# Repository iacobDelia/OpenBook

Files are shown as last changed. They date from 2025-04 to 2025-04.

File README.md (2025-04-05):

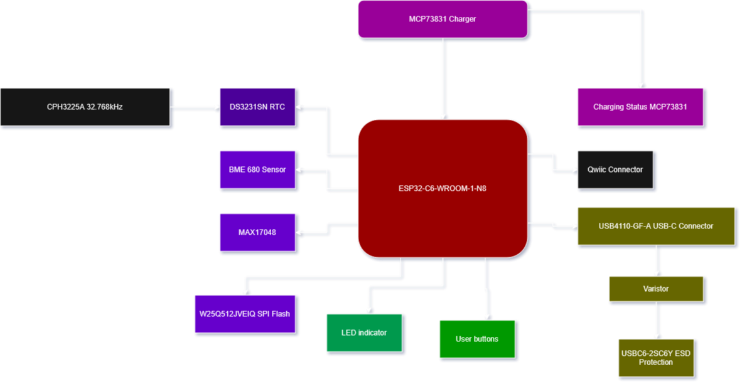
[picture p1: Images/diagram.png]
Diagrama openbook

# Bill of Materials
| Componenta | Link | Datasheet
| --- | --- |---|
| ESP32_WROVER_EAGLE-LTSPICE_RR0402  | https://www.snapeda.com/parts/RC0402FR-07226RL/Yageo/view-part/ |https://www.snapeda.com/parts/RC0402FR-07226RL/Yageo/datasheet/
| QWIIC_CONNECTORJS-1MM | https://www.snapeda.com/parts/PRT-14417/SparkFun/view-part/ |https://www.snapeda.com/parts/PRT-14417/SparkFun%20Electronics/datasheet/
|BUTTON_CUSYOMV1|https://industry.panasonic.com/global/en/downloads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|https://industry.panasonic.com/global/en/downloads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
|ESP32_WROVER_EAGLE-LTSPICE_CC0402|https://componentsearchengine.com/part-view/CC0402MRX5R5BB106/YAGEO|https://componentsearchengine.com/Datasheets/2/CC0402MRX5R5BB106.pdf
|CPH3225A|https://www.snapeda.com/parts/CPH3225A/Seiko+Instruments/view-part/?ref=eda|https://www.snapeda.com/parts/CPH3225A/Seiko%20Instruments/datasheet/|
|ADAFRUIT_LEDCHIP-LED0603|https://www.snapeda.com/parts/KP-1608SURCK/Kingbright/view-part/?ref=search&t=LED%200603|https://www.snapeda.com/parts/KP-1608SURCK/Kingbright/datasheet/
|112A-TAAR-R03_ATTEND|https://store.comet.bg/en/Catalogue/Product/43497/|https://store.comet.bg/en/Catalogue/Product/43497/|
|744043680IND_4828-WE-TPC_WRE|https://www.digikey.sg/en/models/1638515|https://www.we-online.com/components/products/datasheet/744043680.pdf
|BD5229G-TR|https://componentsearchengine.com/part-view/BD5229G-TR/ROHM%20Semiconductor|https://datasheet.datasheetarchive.com/originals/distributors/Datasheets_SAMA/f2b9741ef86007909f138d561a359946.pdf|
|CPH3225A|https://www.snapeda.com/parts/CPH3225A/Seiko+Instruments/view-part/?ref=eda|https://www.snapeda.com/parts/CPH3225A/Seiko%20Instruments/datasheet/|
|DS3231SN|https://www.snapeda.com/parts/DS3231SN%23/Analog+Devices/view-part/?ref=eda|https://www.snapeda.com/parts/DS3231SN%23/Analog%20Devices/datasheet/|
|ESP32-C6-WROOM-1-N8|https://www.snapeda.com/parts/ESP32-C6-WROOM-1-N8/Espressif+Systems/view-part/?ref=eda|https://www.snapeda.com/parts/ESP32-C6-WROOM-1-N8/Espressif%20Systems/datasheet/
|MCP73831|https://www.digikey.com/en/models/1874108|https://ww1.microchip.com/downloads/aemDocuments/documents/APID/ProductDocuments/DataSheets/MCP73831-Family-Data-Sheet-DS20001984H.pdf|
|ESP32_WROVER_BME680_BME680|https://www.snapeda.com/parts/BME680/Bosch/view-part/?welcome=home|https://www.snapeda.com/parts/BME680/Bosch%20Sensortec/datasheet/|
|ESP32_WROVER_EAGLE-LTSPICE_CC0402|https://componentsearchengine.com/Datasheets/2/CC0402MRX5R5BB106.pdf|https://componentsearchengine.com/part-view/CC0402MRX5R5BB106/YAGEO|
|ESP32_WROVER_SPARKFUN-DISCRETESEMI_MOSFET_PCH-DMG2305UX-7|https://componentsearchengine.com/part-view/DMG2305UX-7/Diodes%20Incorporated|https://www.diodes.com//assets/Datasheets/DMG2305UX.pdf|
|ESP32C6_VARISTORCN1812|https://www.mouser.co.uk/ProductDetail/EPCOS-TDK/B72520T0350K062?qs=dEfas%2FXlABIszF52uu7vrg%3D%3D|https://www.tdk-electronics.tdk.com/inf/75/db/CTVS_14/Surge_protection_series.pdf|
|FH34SRJ-24S-0.5SH_99_|https://componentsearchengine.com/part-view/XC6220A331MR-G/Torex|https://product.torexsemi.com/system/files/series/xc6220.pdf|
|MAX17048G+T10|https://www.snapeda.com/parts/MAX17048G+T10/Analog+Devices/view-part/?ref=eda|https://www.snapeda.com/parts/MAX17048G+T10/Analog%20Devices/datasheet/|
|MBR0530|https://ro.mouser.com/ProductDetail/KYOCERA-AVX/SD0805S020S1R0?qs=jCA%252BPfw4LHbpkAoSnwrdjw%3D%3D|https://ro.mouser.com/datasheet/2/40/schottky-3165252.pdf|
|PGB1010603MR|https://www.snapeda.com/parts/PGB1010603MR/Littelfuse/view-part/?ref=eda|https://www.snapeda.com/parts/PGB1010603MR/Littelfuse%20Inc./datasheet/|
|RCL_CPOL-EUCT3528|https://ro.mouser.com/ProductDetail/Vishay-Sprague/TR3B106K025C1300?qs=jCGqFXxTmLdffnuDkXzk1g%3D%3D|https://www.vishay.com/docs/40080/tr3.pdf|
|SAMACSYS_PARTS_USB4110-GF-A|https://componentsearchengine.com/part-view/USB4110-GF-A/GCT%20(GLOBAL%20CONNECTOR%20TECHNOLOGY)|https://gct.co/files/drawings/usb4110.pdf|
|SI1308EDL-T1-GE3|https://componentsearchengine.com/part-view/SI1308EDL-T1-GE3/Vishay|https://componentsearchengine.com/Datasheets/1/SI1308EDL-T1-GE3.pdf|
|SJ|https://grabcad.com/library/solder-jumpers-1||
|USBLC6-2SC6Y|https://www.snapeda.com/parts/USBLC6-2SC6Y/STMicroelectronics/view-part/?ref=eda|https://www.snapeda.com/parts/USBLC6-2SC6Y/STMicroelectronics/datasheet/|
|W25Q512JVEIQ|https://www.snapeda.com/parts/W25Q512JVEIQ/Winbond+Electronics/view-part/?ref=eda|https://www.snapeda.com/parts/W25Q512JVEIQ/Winbond%20Electronics/datasheet/|
|XC6220A331MR-G|https://componentsearchengine.com/part-view/XC6220A331MR-G/Torex|https://product.torexsemi.com/system/files/series/xc6220.pdf|

# Functionalitati Hardware
## Microcontroller
Microcontroller principal: ESP32-C6-WROOM-1-N8

    Interfețe: UART, I²C, SPI, GPIO, ADC, PWM, USB 2.0

    Comunicare wireless: WiFi 6 (802.11ax), Bluetooth 5.0 Low Energy, Zigbee & Thread (prin IEEE 802.15.4)

    Memorie: 8 MB Flash

    Rol: Controler central ce gestionează comunicația cu toate perifericele și modulele externe. Este responsabil pentru achiziția de date, procesare și trimiterea lor către o interfață (de ex. server sau aplicație mobilă).

Ceas în timp real: DS3231SN

    Tip: RTC (Real-Time Clock) cu compensare termică

    Interfață: I²C

    Rol: Asigură măsurarea precisă a timpului, util pentru timestamp-ul datelor colectate de senzori.

Senzor de mediu: BME680

    Măsoară: Temperatură, presiune, umiditate și compuși organici volatili (VOC)

    Interfață: I²C (poate fi și SPI)

    Rol: Oferă date esențiale de mediu pentru aplicații IoT, monitorizare atmosferică etc.

### Managementul energiei
MCP73831

    Rol: Încărcător Li-Ion / Li-Po

    Interfață: Analogică, configurabilă prin rezistențe externe

    Caracteristici: Control al curentului de încărcare, protecții integrate

MAX17048G+T10

    Rol: Fuel Gauge IC

    Interfață: I²C

    Funcții: Măsoară tensiunea și estimează nivelul bateriei (SoC - state of charge)

Memorie externă: W25Q512JVEIQ

    Tip: NOR Flash, 512Mbit

    Interfață: SPI

    Rol: Stocare de date (loguri, configurări, firmware OTA)

Protecție și integritate electrică

    USBLC6-2SC6Y – Protecție ESD pentru liniile USB

    PGB1010603MR – Protecție împotriva descărcărilor electrostatice (ESD)

    SI1308EDL-T1-GE3 / DMG2305UX-7 – MOSFET pentru comutarea energiei sau protecție

    BD5229G-TR – Regulator LDO de 2.9V

    Varistor CN1812 (B72520T0350K062) – Protecție la supratensiuni

    Diodă Schottky (MBR0530) – Prevenirea curenților inversi

Conectivitate externă

    QWIIC_CONNECTORJS-1MM – Conector pentru I²C (QWIIC standard, modular, plug-and-play)

    SAMACSYS_PARTS_USB4110-GF-A – USB-C pentru alimentare și comunicare

    112A-TAAR-R03_ATTEND – Conector placă-la-placă

    SJ (Solder Jumpers) – Permite configurarea opțională a traseelor prin punți de lipit

Feedback vizual & control

    ADAFRUIT_LEDCHIP-LED0603 (KP-1608SURCK) – LED de status

    BUTTON_CUSYOMV1 (EVQPUJ02K) – Buton mecanic, folosit pentru reset, input de utilizator sau inițierea unei funcții

# Total consum
Componentă|	Consum tipic|
|-------|----------|
|ESP32-C6|	~130mA |
|BME680|	~3.1µA (low power)|	
|DS3231SN|	~200nA	|
|MAX17048|	~23µA	|
|MCP73831|	până la 500mA|	
|LED-uri|	~2-10mA	|

Total estimativ în mod activ: ~150-180mA

## Conexiuni componente la pini ESP32-C6
RTC – DS3231SN

    Interfață: I²C

    Pini ESP32-C6 folosiți:

        GPIO8 – I²C SDA

        GPIO9 – I²C SCL

    Motiv: GPIO8 și GPIO9 sunt frecvent utilizați pentru magistrala I²C pe ESP32-C6 deoarece pot fi configurate software și sunt ușor de accesat. SDA și SCL trebuie trase cu rezistențe de pull-up (tipic 4.7kΩ).

Senzor mediu – BME680

    Interfață: I²C (partajează magistrala cu DS3231)

    Pini ESP32-C6 folosiți:

        GPIO8 – SDA

        GPIO9 – SCL

    Motiv: Magistrala I²C permite conectarea în paralel a mai multor dispozitive, fiecare având adresă unică.

Fuel Gauge – MAX17048

    Interfață: I²C

    Pini: Aceeași magistrală I²C (GPIO8 & GPIO9)

    Motiv: MAX17048 are adresă I²C fixă, deci trebuie verificat să nu fie conflict cu celelalte două componente (nu e cazul aici).

Memorie externă – W25Q512JVEIQ

    Interfață: SPI

    Pini ESP32-C6:

        GPIO4 – SPI MOSI

        GPIO5 – SPI MISO

        GPIO6 – SPI CLK

        GPIO7 – SPI CS

    Motiv: Aceste GPIO-uri sunt pinii SPI hardware dedicați pe ESP32-C6 și asigură performanță maximă și compatibilitate cu interfața SPI (QSPI în cazul memoriei).

LED (KP-1608SURCK)

    Interfață: GPIO (digital out, cu rezistor în serie)

    Pin:

        GPIO3 – LED Control

    Motiv: GPIO3 este un pin liber cu capabilități PWM, ceea ce permite și control al intensității (dimming), nu doar on/off.

Buton (EVQPUJ02K)

    Interfață: GPIO + Pull-up intern

    Pin:

        GPIO0 – Buton utilizator

    Motiv: GPIO0 este adesea folosit și pentru bootloader/reset (cu atenție la stări în timpul pornirii). E un pin convenabil pentru input digital.

Qwiic Connector (I²C extensibil)

    Pini: I²C SDA/SCL partajați

        GPIO8 – SDA

        GPIO9 – SCL

    Motiv: Qwiic folosește același protocol I²C, deci toate dispozitivele compatibile Qwiic se pot lega în paralel la acești pini.

MCP73831 – Încărcare baterie

    Pini:

        VBUS / USB – Alimentare 5V

        STAT pin legat la GPIO10 (monitorizare charging status)

    Motiv: GPIO10 este configurabil ca input pentru a citi starea de încărcare (LED status al MCP73831 conectat la pinul STAT).

MAX17048 – Fuel Gauge

    Alimentare + I²C (vezi mai sus)

    INT (optional): Conectat la GPIO1

    Motiv: GPIO1 poate fi configurat cu întrerupere (interrupt) pentru notificări despre nivelul bateriei critic/scăzut.

USB4110-GF-A – USB-C connector

    Funcție: Alimentare 5V și comunicație

    Pin USB D+ / D- conectați la:

        GPIO18 – USB D+

        GPIO19 – USB D-

    Motiv: ESP32-C6 are suport USB nativ. Aceste GPIO-uri sunt default pentru perifericul USB Device.

Alte conexiuni:

    CPH3225A (oscilator 32.768 kHz) – utilizat pentru RTC, conectat la pinul dedicat RTC_CLKIN (sau la DS3231 dacă nu e folosit direct de MCU)

    MOSFET & diodă Schottky – control și protecție, comutarea pinilor GPIO pentru pornire/oprire module

    Varistor, rezistențe, condensatori – pasive pentru protecție, filtrare și stabilitate electrică (nu folosesc GPIO-uri direct)

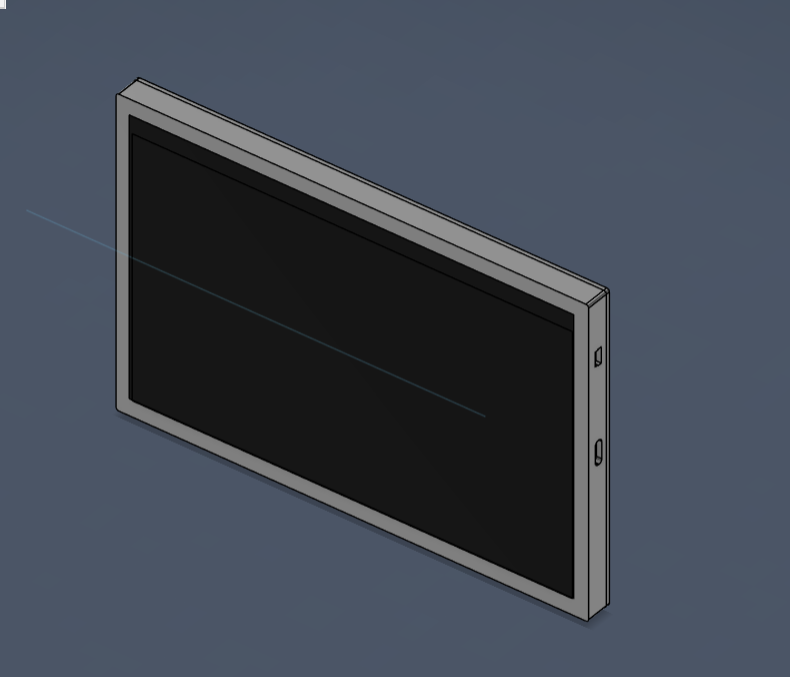
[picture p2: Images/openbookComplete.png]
Render complet

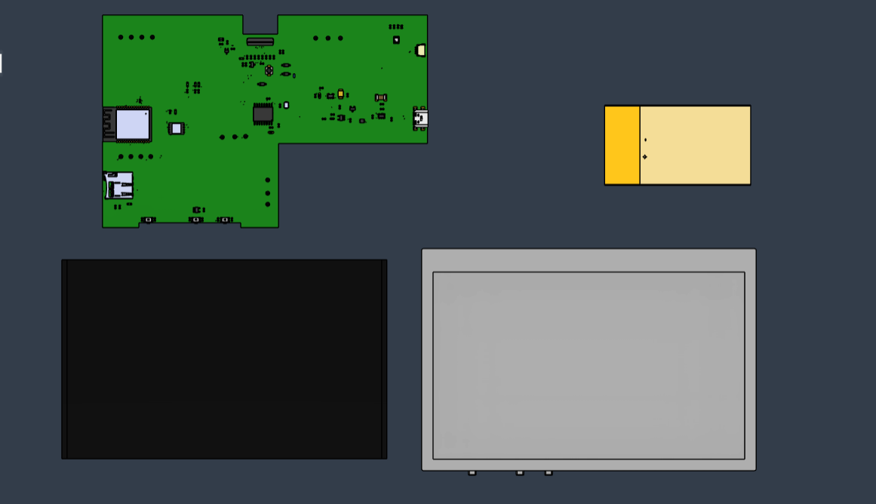
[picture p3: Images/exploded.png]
Exploded view

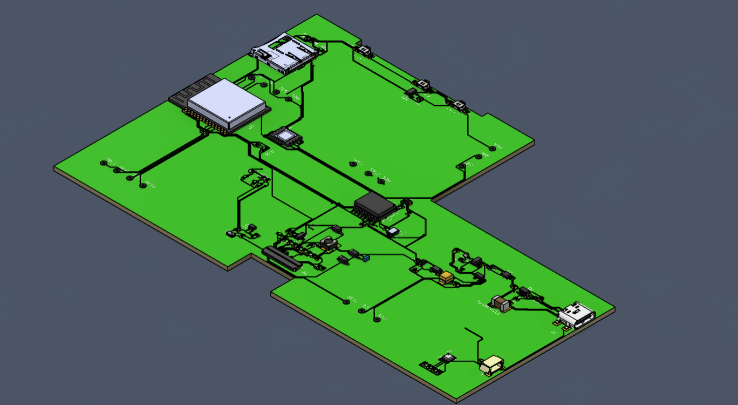
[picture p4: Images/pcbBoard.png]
Pcb


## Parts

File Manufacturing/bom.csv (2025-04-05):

Qty | Value | Device | Package | Parts | Description | ARROW_PART_NUMBER | ARROW_PRICE-STOCK | AVAILABILITY | CENTROID_NOT_SPECIFIED | CHECK_PRICES | COPYRIGHT | DATASHEET | DESCRIPTION | DIGIKEY_DESCRIPTION | DIGIKEY_PART_NUMBER | HEIGHT | LEAD_FREE | MANUFACTURER_NAME | MANUFACTURER_PART_NUMBER | MF | MFR_NAME | MOUSER_PART_NUMBER | MOUSER_PRICE-STOCK | MOUSER_TESTING_PART_NUMBER | MOUSER_TESTING_PRICE-STOCK | MP | MPN | PACKAGE | POPULARITY | PREFIX | PRICE | PROD_ID | PURCHASE-URL | ROHS | SNAPEDA_LINK | SPICEMODEL | SPICEPREFIX | TEMPERATURE_RANGE_HIGH | TEMPERATURE_RANGE_LOW | TP_SIGNAL_NAME | VALUE
1 |  | ADAFRUIT_LEDCHIP-LED0603 | ADAFRUIT_CHIP-LED0603 | CHG_LED | LED
1 |  | SJ | SJ | SJ1 | SMD solder JUMPER |  |  |  |  |  |  |  |  |  |  |  |  |  |  |  |  |  |  |  |  |  |  |  | 3
8 | 0.1uF/50V | ESP32_WROVER_EAGLE-LTSPICE_CC0402 | ESP32_WROVER_EAGLE-LTSPICE_C0402 | EPD_C5, EPD_C6, EPD_C7, EPD_C8, EPD_C9, EPD_C10, EPD_C11, EPD_C12 | CAPACITOR, European symbol |  |  |  |  |  |  |  |  |  |  |  |  |  |  |  |  |  |  |  |  |  |  |  |  |  |  |  |  |  |  | NONE | C
1 | 0.47 | ESP32_WROVER_EAGLE-LTSPICE_RR0402 | ESP32_WROVER_EAGLE-LTSPICE_R0402 | R3 | RESISTOR, European symbol |  |  |  |  |  |  |  |  |  |  |  |  |  |  |  |  |  |  |  |  |  |  |  |  |  |  |  |  |  |  | NONE | R
1 | 100K | ESP32_WROVER_EAGLE-LTSPICE_RR0402 | ESP32_WROVER_EAGLE-LTSPICE_R0402 | R1_PWRUSB | RESISTOR, European symbol
6 | 100nF | ESP32_WROVER_EAGLE-LTSPICE_CC0402 | ESP32_WROVER_EAGLE-LTSPICE_C0402 | C1, C2, C4_USB, C7, C8, C_DELAY | CAPACITOR, European symbol |  |  |  |  |  |  |  |  |  |  |  |  |  |  |  |  |  |  |  |  |  |  |  |  |  |  |  |  |  |  | NONE | C
1 | 100uF TANT | RCL_CPOL-EUCT3528 | RCL_CT3528 | C11 | POLARIZED CAPACITOR, European symbol |  |  |  |  |  |  |  |  |  |  |  |  |  |  |  |  |  |  |  |  |  |  |  | 0 |  |  |  |  |  |  |  | C
13 | 10K | ESP32_WROVER_EAGLE-LTSPICE_RR0402 | ESP32_WROVER_EAGLE-LTSPICE_R0402 | R1_PINH, R1_PINH1, R2-PINH, R2-PINH1, R5, R6, R7, R8, R9, R10, R_BOOT, R_CHANGE, R_RESET | RESISTOR, European symbol
2 | 10k | ESP32_WROVER_EAGLE-LTSPICE_RR0402 | ESP32_WROVER_EAGLE-LTSPICE_R0402 | R1, R_CL1 | RESISTOR, European symbol
1 | 10k | ESP32_WROVER_EAGLE-LTSPICE_RR0402 | ESP32_WROVER_EAGLE-LTSPICE_R0402 | R4 | RESISTOR, European symbol |  |  |  |  |  |  |  |  |  |  |  |  |  |  |  |  |  |  |  |  |  |  |  |  |  |  |  |  |  |  | NONE | R
4 | 10uF | ESP32_WROVER_EAGLE-LTSPICE_CC0402 | ESP32_WROVER_EAGLE-LTSPICE_C0402 | C3, C5, C6, C10 | CAPACITOR, European symbol |  |  |  |  |  |  |  |  |  |  |  |  |  |  |  |  |  |  |  |  |  |  |  |  |  |  |  |  |  |  | NONE | C
1 | 112A-TAAR-R03_ATTEND | 112A-TAAR-R03_ATTEND | 112ATAARR03ATTEND | J4 | Micro SD Card Socket, Push-Push Type, Top Mount, SMT, H=1.83mm, 10u |  |  |  |  |  |  |  | Micro SD Card Socket | Push-Push Type | Top Mount | SMT | H=1.83mm | 10u |  |  | 1.9mm |  | ATTEND | 112A-TAAR-R03 ATTEND
1 | 15 | ESP32_WROVER_EAGLE-LTSPICE_RR0402 | ESP32_WROVER_EAGLE-LTSPICE_R0402 | R_CAPACITOR | RESISTOR, European symbol
2 | 1uF/50V | ESP32_WROVER_EAGLE-LTSPICE_CC0402 | ESP32_WROVER_EAGLE-LTSPICE_C0402 | EPD_C1, EPD_C2 | CAPACITOR, European symbol |  |  |  |  |  |  |  |  |  |  |  |  |  |  |  |  |  |  |  |  |  |  |  |  |  |  |  |  |  |  | NONE | C
1 | 2.2 | ESP32_WROVER_EAGLE-LTSPICE_RR0402 | ESP32_WROVER_EAGLE-LTSPICE_R0402 | R2 | RESISTOR, European symbol
1 | 200 | ESP32_WROVER_EAGLE-LTSPICE_RR0402 | ESP32_WROVER_EAGLE-LTSPICE_R0402 | R1_BAT | RESISTOR, European symbol
2 | 20V/4.2A/52mO/1.4W | ESP32_WROVER_SPARKFUN-DISCRETESEMI_MOSFET_PCH-DMG2305UX-7 | ESP32_WROVER_SPARKFUN-DISCRETESEMI_SOT23-3 | Q2, Q3 | P-channel MOSFETs |  |  |  |  |  |  |  |  |  |  |  |  |  |  |  |  |  |  |  |  |  |  |  |  |  |  | TRAN-14388 |  |  |  |  |  |  |  |  | 20V/4.2A/52mO/1.4W
1 | 2k | ESP32_WROVER_EAGLE-LTSPICE_RR0402 | ESP32_WROVER_EAGLE-LTSPICE_R0402 | R2_BAT | RESISTOR, European symbol
5 | 4.7uF | ESP32_WROVER_EAGLE-LTSPICE_CC0402 | ESP32_WROVER_EAGLE-LTSPICE_C0402 | C1_BAT, C1_BAT1, C1_BAT2, C2_BAT, C5_USB | CAPACITOR, European symbol |  |  |  |  |  |  |  |  |  |  |  |  |  |  |  |  |  |  |  |  |  |  |  |  |  |  |  |  |  |  | NONE | C
1 | 4.7uF/25V | ESP32_WROVER_EAGLE-LTSPICE_CC0402 | ESP32_WROVER_EAGLE-LTSPICE_C0402 | C4 | CAPACITOR, European symbol |  |  |  |  |  |  |  |  |  |  |  |  |  |  |  |  |  |  |  |  |  |  |  |  |  |  |  |  |  |  | NONE | C
1 | 5K1 | ESP32_WROVER_EAGLE-LTSPICE_RR0402 | ESP32_WROVER_EAGLE-LTSPICE_R0402 | R2-USB1 | RESISTOR, European symbol
1 | 5k1 | ESP32_WROVER_EAGLE-LTSPICE_RR0402 | ESP32_WROVER_EAGLE-LTSPICE_R0402 | R2-USB | RESISTOR, European symbol
1 | 68uH | 744043680IND_4828-WE-TPC_WRE | IND_4828-WE-TPC_WRE | L1 |  |  |  |  |  |  | Copyright (C) 2024 Ultra Librarian. All rights reserved. |  |  |  |  |  |  |  | 744043680 |  | Wurth Electronics
1 | BD5229G-TR | BD5229G-TR | SOT95P280X125-5N | IC1 | Voltage Detector with Adjustable Delay Time: CMOS processes are utilized to develop high precision, low current consumption CMOS reset ICs that allow arbitrary setting of the delay time. The extensive lineup includes both Nch Open Drain and CMOS output types in a wide range of detection voltages (from 2.3V to 6.0V, in 0.1V steps), enabling selection of the ideal solution based on customer requirements. In addition, the entire series is of course both lead-free and RoHS-compliant. |  |  |  |  |  |  |  | Voltage Detector with Adjustable Delay Time: CMOS processes are utilized to develop high precision | low current consumption CMOS reset ICs that allow arbitrary setting of the delay time. The extensive lineup includes both Nch Open Drain and CMOS output types in a wide range of detection voltages (from 2.3V to 6.0V | in 0.1V steps) | enabling selection of the ideal solution based on customer requirements. In addition | the entire series is of course both lead-free and RoHS-compliant. |  |  | 1.25mm |  | ROHM Semiconductor | BD5229G-TR |  |  | 755-BD5229G-TR | https://www.mouser.co.uk/ProductDetail/ROHM-Semiconductor/BD5229G-TR?qs=4kLU8WoGk0vvnhrrYwdszw%3D%3D
3 | BUTTON_CUSYOMV1 | BUTTON_CUSYOMV1 | MYBUTTON | BOOT_BUTTON, CHANGE_BUTTON, RESET_BUTTON
1 | CPH3225A | CPH3225A | CAPCP3225X100N | C10_SUPERCAP | Cap 0.011F 3.3V 1210 Flat Check availability |  |  | Not in stock |  | https://www.snapeda.com/parts/CPH3225A/Seiko+Instruments/view-part/?ref=eda |  |  | 11 mF (EDLC) Supercapacitor 3.3 V 1210 (3225 Metric) - - |  |  |  |  |  |  | Seiko Instruments |  |  |  |  |  | CPH3225A |  | 1210 Seiko |  |  | None |  | https://www.snapeda.com/api/url_track_click_mouser/?unipart_id=562593&manufacturer=Seiko Instruments&part_name=CPH3225A&search_term=None |  | https://www.snapeda.com/parts/CPH3225A/Seiko+Instruments/view-part/?ref=snap
1 | DS3231SN# | DS3231SN# | SOIC127P1032X265-16N | U3 | Real Time Clock Serial 16-Pin SOIC W T/R Check availability |  |  | In Stock |  | https://www.snapeda.com/parts/DS3231SN%23/Analog+Devices/view-part/?ref=eda |  |  | Extremely Accurate I²C-Integrated RTC/TCXO/Crystal |  |  |  |  |  |  | Analog Devices |  |  |  |  |  | DS3231SN# |  | SOIC-16 Maxim |  |  | None |  | https://www.snapeda.com/api/url_track_click_mouser/?unipart_id=99048&manufacturer=Analog Devices&part_name=DS3231SN#&search_term=None |  | https://www.snapeda.com/parts/DS3231SN%23/Analog+Devices/view-part/?ref=snap
1 | ESP32-C6-WROOM-1-N8 | ESP32-C6-WROOM-1-N8 | XCVR_ESP32-C6-WROOM-1-N8 | U2 | Check availability |  |  | In Stock |  | https://www.snapeda.com/parts/ESP32-C6-WROOM-1-N8/Espressif+Systems/view-part/?ref=eda |  |  | Multiprotocol Modules ESP32-C6 module | Wi-Fi 6 in 2.4 GHz band | Bluetooth 5 | Zigbee 3.0 and Thread. ESP34-WROOM Compatible - ENGINEERING SAMPLE |  |  |  |  |  |  | Espressif Systems |  |  |  |  |  | ESP32-C6-WROOM-1-N8 |  | None |  |  | None |  |  |  | https://www.snapeda.com/parts/ESP32-C6-WROOM-1-N8/Espressif+Systems/view-part/?ref=snap
1 | ESP32C6_VARISTORCN1812 | ESP32C6_VARISTORCN1812 | ESP32C6_VARISTOR_CT/CN1812 | PFMF.050.1 | VARISTOR |  |  |  |  |  |  |  |  |  |  |  |  |  |  |  |  |  |  |  |  |  |  |  | 0
2 | ESP32_WROVER_AVX---SD0805S020S1R0_AVX_SD0805S020S1R0_0_0AVX_SD0805S020S1R0_0_0 | ESP32_WROVER_AVX---SD0805S020S1R0_AVX_SD0805S020S1R0_0_0AVX_SD0805S020S1R0_0_0 | ESP32_WROVER_AVX---SD0805S020S1R0_AVX_SD0805S020S1R0_0 | D2, D7 | Schottky Barrier Rectifier Diode |  |  |  | No |  |  | http://datasheets.avx.com/schottky.pdf |  | DIODE SCHOTTKY 20V 1A 0805 | 478-7800-1-ND |  | yes |  |  | AVX |  | 581-SD0805S020S1R0 |  |  |  |  |  | 0805 (2012 metric) |  | D |  |  |  | yes |  |  |  | +125°C | -55°C
1 | ESP32_WROVER_BME680_BME680 | ESP32_WROVER_BME680_BME680 | ESP32_WROVER_BME680_PSON80P300X300X100-8N | SENSOR2 | Integrated Environmental Unit |  |  | Unavailable |  |  |  |  | Integrated Environmental Unit |  |  |  |  |  |  | Bosch Sensortec |  |  |  |  |  | BME680 |  | LGA-8 Bosch Tools |  |  | None
1 | ESP32_WROVER_SPARKFUN-IC-POWER_MCP73831 | ESP32_WROVER_SPARKFUN-IC-POWER_MCP73831 | ESP32_WROVER_SPARKFUN-IC-POWER_SOT23-5 | MCP73831 | MCP73831T Li-Ion, Li-Pol Controller |  |  |  |  |  |  |  |  |  |  |  |  |  |  |  |  |  |  |  |  |  |  |  |  |  |  | IC-09995
1 | FH34SRJ-24S-0.5SH_99_ | FH34SRJ-24S-0.5SH_99_ | FH34SRJ24S05SH99 | J1 | (0.50mm) Surface Mount, Right Angle |  |  |  |  |  |  |  | 24 Position FFC | FPC Connector Contacts | (0.50mm) Surface Mount | Right Angle |  |  | 1.1mm |  | Hirose | FH34SRJ-24S-0.5SH(99) |  |  | 798-FH34SRJ24S05SH99 | https://www.mouser.co.uk/ProductDetail/Hirose-Connector/FH34SRJ-24S-0.5SH99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
1 | MAX17048G+T10 | MAX17048G+T10 | SON50P200X200X80-9N | U4 | Check availability |  |  | In Stock |  | https://www.snapeda.com/parts/MAX17048G+T10/Analog+Devices/view-part/?ref=eda |  |  | 3µA 1-Cell/2-Cell Fuel Gauge with ModelGauge |  |  |  |  |  |  | Analog Devices |  |  |  |  |  | MAX17048G+T10 |  | TDFN-8 Maxim |  |  | None |  | https://www.snapeda.com/api/url_track_click_mouser/?unipart_id=329239&manufacturer=Analog Devices&part_name=MAX17048G+T10&search_term=None |  | https://www.snapeda.com/parts/MAX17048G+T10/Analog+Devices/view-part/?ref=snap
3 | MBR0530 | MBR0530 | SOD3716X135N | D3, D4, D5 | ON SEMICONDUCTOR - MBR0530 - DIODE, SCHOTTKY, 0.5A, 30V, SOD-123 |  |  | In Stock |  | https://www.snapeda.com/parts/MBR0530/Onsemi/view-part/?ref=eda |  |  | Diode Schottky 30 V 500mA Surface Mount SOD-123 |  |  |  |  |  |  | ON Semiconductor |  |  |  |  |  | MBR0530 |  | SOD-123-2 ON Semiconductor |  |  | None |  | https://www.snapeda.com/api/url_track_click_mouser/?unipart_id=179458&manufacturer=ON Semiconductor&part_name=MBR0530&search_term=None |  | https://www.snapeda.com/parts/MBR0530/Onsemi/view-part/?ref=snap
6 | PGB1010603MR | PGB1010603MR | DIOC1608X36N | D6, D8, D9, D10, D11, D12 | Check availability |  |  | In Stock |  | https://www.snapeda.com/parts/PGB1010603MR/Littelfuse/view-part/?ref=eda |  |  | 150V (Typ) Clamp - Ipp Tvs Diode Surface Mount 0603 (1608 Metric) |  |  |  |  |  |  | Littelfuse Inc. |  |  |  |  |  | PGB1010603MR |  | 0603 Littelfuse Inc. |  |  | None |  | https://www.snapeda.com/api/url_track_click_mouser/?unipart_id=5659453&manufacturer=Littelfuse Inc.&part_name=PGB1010603MR&search_term=None |  | https://www.snapeda.com/parts/PGB1010603MR/Littelfuse/view-part/?ref=snap
1 | QWIIC_RIGHT_ANGLE | QWIIC_CONNECTORJS-1MM | JST04_1MM_RA | J3 | SparkFun I2C Standard Qwiic Connector |  |  |  |  |  |  |  |  |  |  |  |  |  |  |  |  |  |  |  |  |  |  |  |  |  |  | CONN-13694 |  |  |  |  |  |  |  |  | QWIIC_RIGHT_ANGLE
1 | SAMACSYS_PARTS_USB4110-GF-A | SAMACSYS_PARTS_USB4110-GF-A | SAMACSYS_PARTS_USB4110GFA | J2 | CONN USB 2.0 TYPE-C R/A SMT |  |  |  |  |  |  |  | CONN USB 2.0 TYPE-C R/A SMT |  |  | 3.26mm |  | GCT (GLOBAL CONNECTOR TECHNOLOGY) | USB4110-GF-A |  |  | 640-USB4110-GF-A | https://www.mouser.co.uk/ProductDetail/GCT/USB4110-GF-A?qs=KUoIvG%2F9IlYiZvIXQjyJeA%3D%3D
1 | SI1308EDL-T1-GE3 | SI1308EDL-T1-GE3 | SOT65P210X110-3N | Q1 | MOSFET N-Ch 30V 1.5A TrenchFET SC70 Vishay Si1308EDL-T1-GE3 N-channel MOSFET Transistor, 1.5 A, 30 V, 3-Pin SC-70 |  |  | In Stock |  | https://www.snapeda.com/parts/SI1308EDL-T1-GE3/Vishay+Siliconix/view-part/?ref=eda |  |  | Si1308EDL-T1-GE3 N-channel MOSFET Transistor | 1.5 A | 30 V | 3-Pin SC-70 | Siliconix / Vishay SI1308EDL-T1-GE3 |  |  |  |  |  |  | Vishay Siliconix |  |  |  |  |  | SI1308EDL-T1-GE3 |  | SOT-323 Vishay Semiconductor |  |  | None |  | https://www.snapeda.com/api/url_track_click_mouser/?unipart_id=274603&manufacturer=Vishay Siliconix&part_name=SI1308EDL-T1-GE3&search_term=None |  | https://www.snapeda.com/parts/SI1308EDL-T1-GE3/Vishay+Siliconix/view-part/?ref=snap
17 | TPTP20R | TPTP20R | TP20R | TP1, TP2, TP3, TP4, TP5, TP6, TP7, TP8, TP9, TP10, TP11, TP12, TP13, TP14, TP15, TP16, TP17 | Test pad |  |  |  |  |  |  |  |  |  |  |  |  |  |  |  |  |  |  |  |  |  |  |  | 2
1 | USBLC6-2SC6Y | USBLC6-2SC6Y | SOT95P280X145-6N | D1 | Low Cap. ESD Protection Auto SOT-23-6 STMicroelectronics USBLC6-2SC6Y, Dual Uni-Directional TVS Diode Array, 6-Pin SOT-23 |  |  | In Stock |  | https://www.snapeda.com/parts/USBLC6-2SC6Y/STMicroelectronics/view-part/?ref=eda |  |  | 17V Clamp 5A (8/20µs) Ipp Tvs Diode Surface Mount SOT-23-6 |  |  |  |  |  |  | STMicroelectronics |  |  |  |  |  | USBLC6-2SC6Y |  | SOT-23-6 STMicroelectronics |  |  | None |  |  |  | https://www.snapeda.com/parts/USBLC6-2SC6Y/STMicroelectronics/view-part/?ref=snap
1 | W25Q512JVEIQ | W25Q512JVEIQ | SON127P600X800X80-9N | U1 | Check availability |  |  | In Stock |  | https://www.snapeda.com/parts/W25Q512JVEIQ/Winbond+Electronics/view-part/?ref=eda |  |  | FLASH - NOR Memory IC 512Mb (64M x 8) SPI - Quad I/O 133 MHz 8-WSON (8x6) |  |  |  |  |  |  | Winbond Electronics |  |  |  |  |  | W25Q512JVEIQ |  | Package |  |  | None |  |  |  | https://www.snapeda.com/parts/W25Q512JVEIQ/Winbond+Electronics/view-part/?ref=snap
1 | XC6220A331MR-G | XC6220A331MR-G | SOT95P280X120-5N | IC2 | LDO Voltage Regulators |  |  |  |  |  |  |  | LDO Voltage Regulators |  |  | 1.2mm |  | Torex | XC6220A331MR-G |  |  | 865-XC6220A331MR-G | https://www.mouser.co.uk/ProductDetail/Torex-Semiconductor/XC6220A331MR-G?qs=AsjdqWjXhJ8ZSWznL1J0gg%3D%3D

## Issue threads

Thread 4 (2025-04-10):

Valori condensatoare de la butoane

bogdan1775, 2025-04-10:
Valoarea condensatoarelor C6 si C10 de la butoane trebuie sa fie de 100 nF, in loc de 10 uF.
Valoarea condensatorului C5 de la butonul de reset trebuie sa fie de 1 uF, in loc de 10 uF.

Closed 2025-04-11.

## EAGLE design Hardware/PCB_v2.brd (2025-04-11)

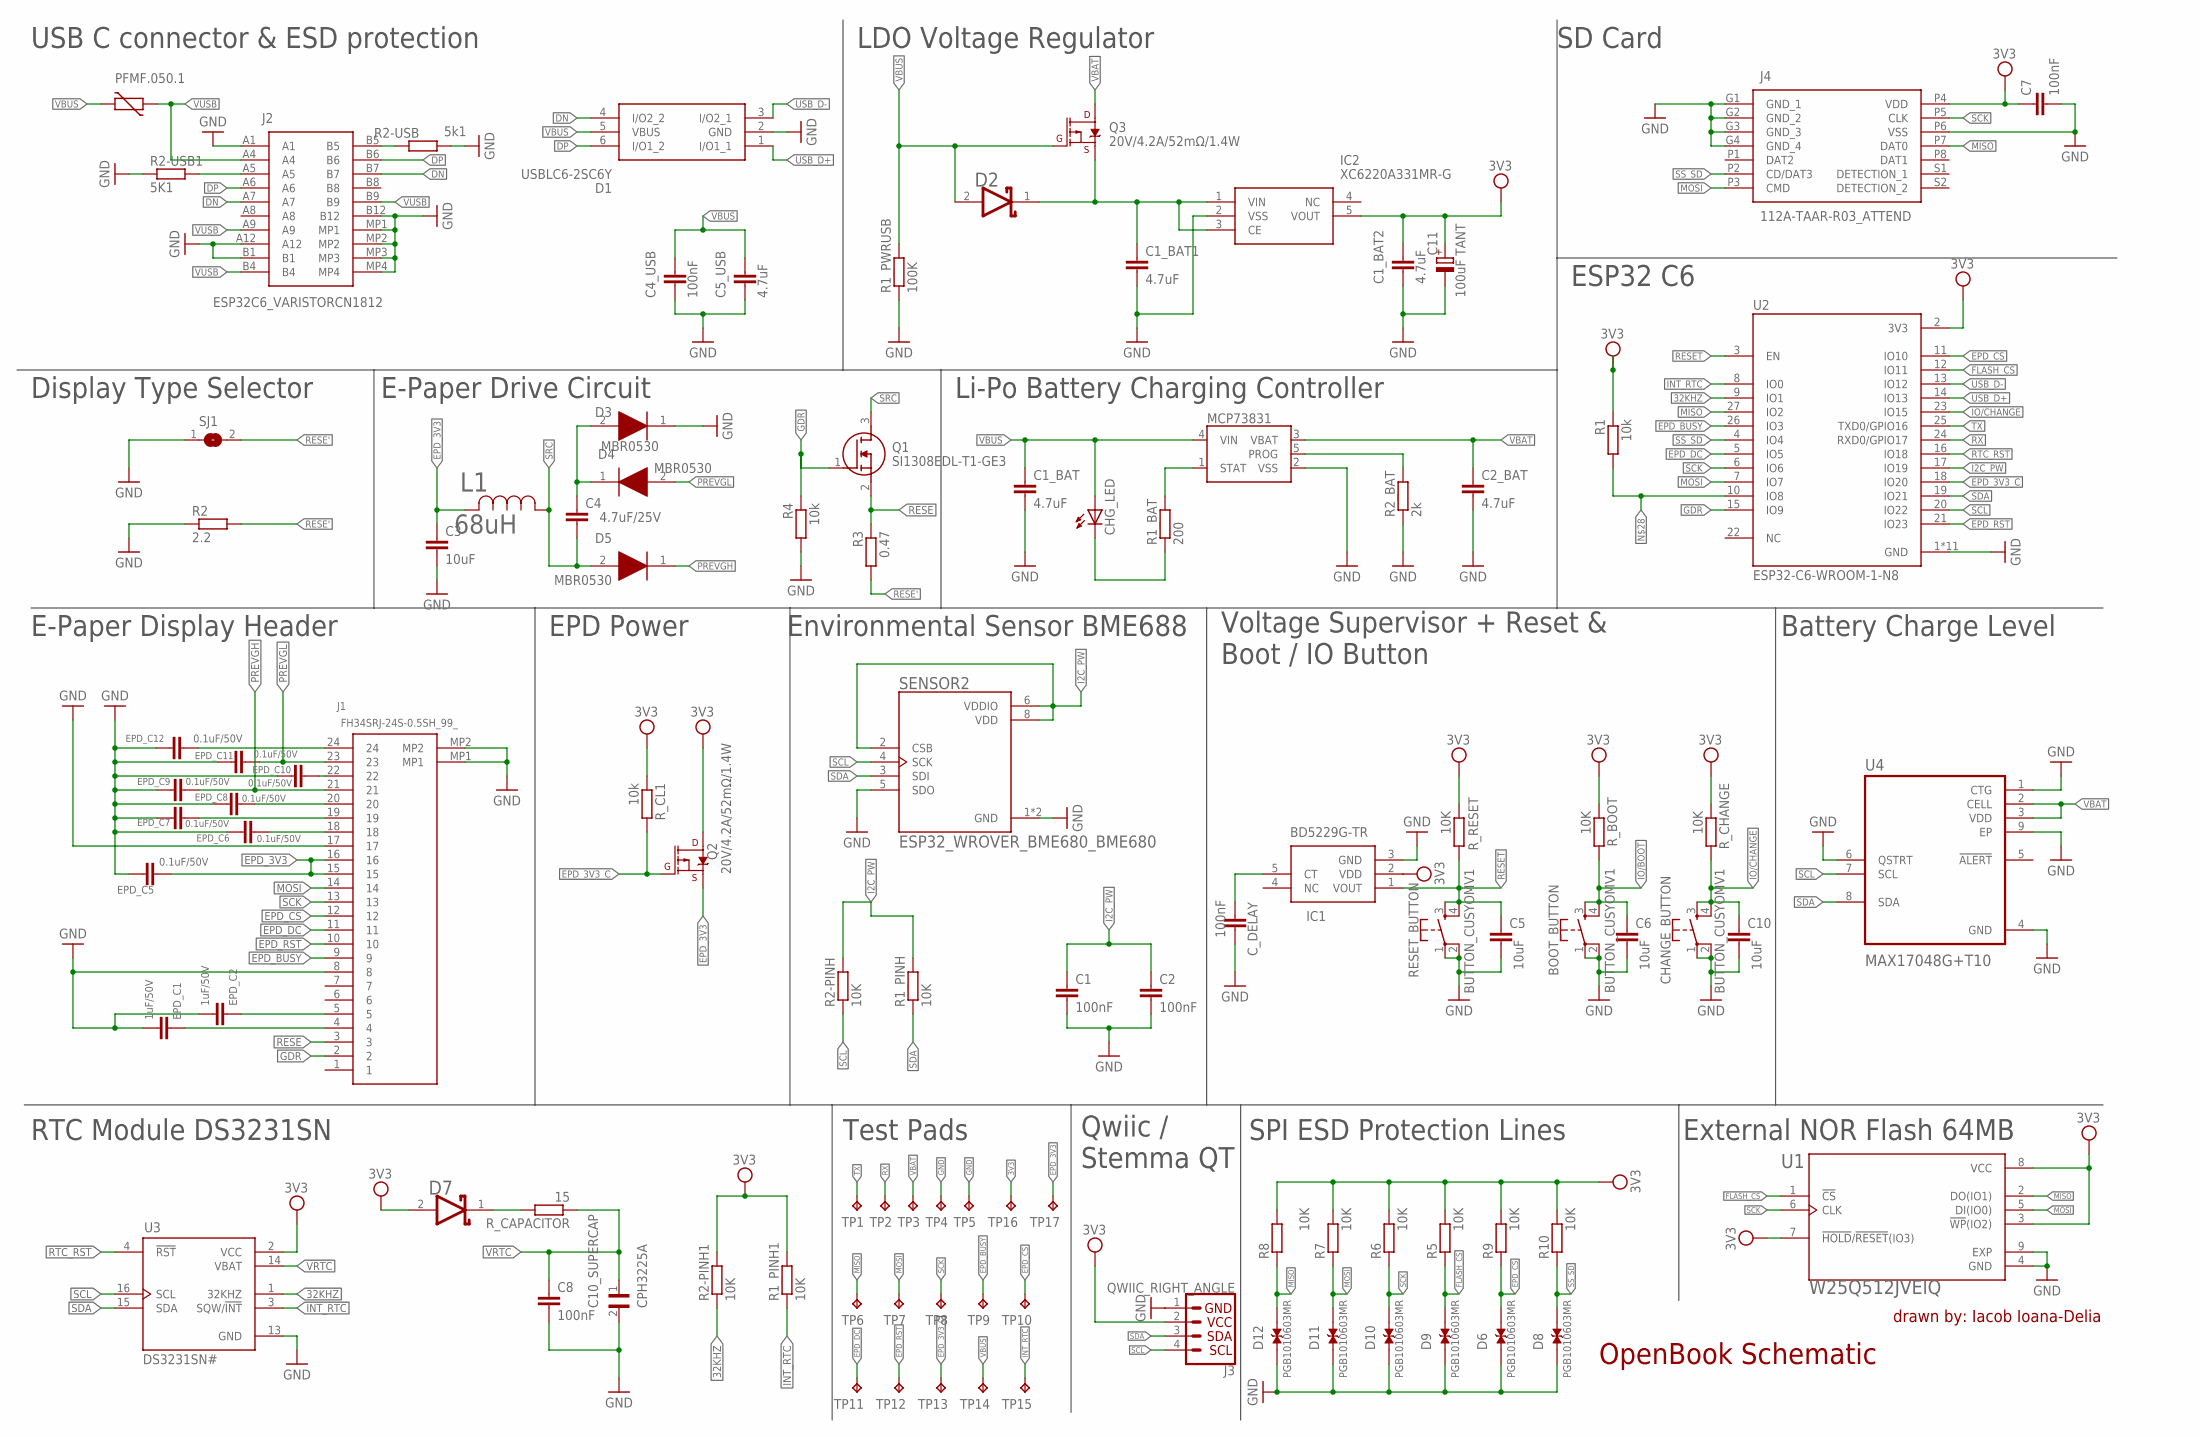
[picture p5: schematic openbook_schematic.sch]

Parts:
BOOT_BUTTON: BUTTON_CUSYOMV1; MYBUTTON
C1, C2, C4_USB, C7, C8: 100nF; ESP32_WROVER_EAGLE-LTSPICE_C0402
C1_BAT, C1_BAT1, C1_BAT2, C2_BAT, C5_USB: 4.7uF; ESP32_WROVER_EAGLE-LTSPICE_C0402
C3, C5, C6, C10: 10uF; ESP32_WROVER_EAGLE-LTSPICE_C0402
C4: 4.7uF/25V; ESP32_WROVER_EAGLE-LTSPICE_C0402
C10_SUPERCAP: CPH3225A; CAPCP3225X100N
C11: 100uF TANT; RCL_CT3528
CHANGE_BUTTON: BUTTON_CUSYOMV1; MYBUTTON
CHG_LED: ADAFRUIT_LEDCHIP-LED0603; ADAFRUIT_CHIP-LED0603
C_DELAY: 100nF; ESP32_WROVER_EAGLE-LTSPICE_C0402
D1: USBLC6-2SC6Y; SOT95P280X145-6N
D2, D7: ESP32_WROVER_AVX---SD0805S020S1R0_AVX_SD0805S020S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; ESP32_WROVER_AVX---SD0805S020S1R0_AVX_SD0805S020S1R0_0
D3, D4, D5: MBR0530; SOD3716X135N
D6, D8, D9, D10, D11, D12: PGB1010603MR; DIOC1608X36N
EPD_C1, EPD_C2: 1uF/50V; ESP32_WROVER_EAGLE-LTSPICE_C0402
EPD_C5, EPD_C6, EPD_C7, EPD_C8, EPD_C9, EPD_C10, EPD_C11, EPD_C12: 0.1uF/50V; ESP32_WROVER_EAGLE-LTSPICE_C0402
IC1: BD5229G-TR; SOT95P280X125-5N
IC2: XC6220A331MR-G; SOT95P280X120-5N
J1: FH34SRJ-24S-0.5SH_99_; FH34SRJ24S05SH99
J2: SAMACSYS_PARTS_USB4110-GF-A; SAMACSYS_PARTS_USB4110GFA
J3: QWIIC_RIGHT_ANGLE; JST04_1MM_RA
J4: 112A-TAAR-R03_ATTEND; 112ATAARR03ATTEND
L1: 68uH; IND_4828-WE-TPC_WRE
MCP73831: ESP32_WROVER_SPARKFUN-IC-POWER_MCP73831; ESP32_WROVER_SPARKFUN-IC-POWER_SOT23-5
PFMF.050.1: ESP32C6_VARISTORCN1812; ESP32C6_VARISTOR_CT/CN1812
Q1: SI1308EDL-T1-GE3; SOT65P210X110-3N
Q2, Q3: 20V/4.2A/52mΩ/1.4W; ESP32_WROVER_SPARKFUN-DISCRETESEMI_SOT23-3
R1, R4: 10k; ESP32_WROVER_EAGLE-LTSPICE_R0402
R1_BAT: 200; ESP32_WROVER_EAGLE-LTSPICE_R0402
R1_PINH, R1_PINH1, R2-PINH, R2-PINH1, R5, R6, R7, R8, R9, R10: 10K; ESP32_WROVER_EAGLE-LTSPICE_R0402
R1_PWRUSB: 100K; ESP32_WROVER_EAGLE-LTSPICE_R0402
R2: 2.2; ESP32_WROVER_EAGLE-LTSPICE_R0402
R2-USB: 5k1; ESP32_WROVER_EAGLE-LTSPICE_R0402
R2-USB1: 5K1; ESP32_WROVER_EAGLE-LTSPICE_R0402
R2_BAT: 2k; ESP32_WROVER_EAGLE-LTSPICE_R0402
R3: 0.47; ESP32_WROVER_EAGLE-LTSPICE_R0402
RESET_BUTTON: BUTTON_CUSYOMV1; MYBUTTON
R_BOOT: 10K; ESP32_WROVER_EAGLE-LTSPICE_R0402
R_CAPACITOR: 15; ESP32_WROVER_EAGLE-LTSPICE_R0402
R_CHANGE: 10K; ESP32_WROVER_EAGLE-LTSPICE_R0402
R_CL1: 10k; ESP32_WROVER_EAGLE-LTSPICE_R0402
R_RESET: 10K; ESP32_WROVER_EAGLE-LTSPICE_R0402
SENSOR2: ESP32_WROVER_BME680_BME680; ESP32_WROVER_BME680_PSON80P300X300X100-8N
SJ1: SJ
TP1, TP2, TP3, TP4, TP5, TP6, TP7, TP8, TP9, TP10, TP11, TP12, TP13, TP14, TP15, TP16, TP17: TPTP20R; TP20R
U1: W25Q512JVEIQ; SON127P600X800X80-9N
U2: ESP32-C6-WROOM-1-N8; XCVR_ESP32-C6-WROOM-1-N8
U3: DS3231SN#; SOIC127P1032X265-16N
U4: MAX17048G+T10; SON50P200X200X80-9N

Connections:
3V3: C1_BAT2.1, C7.1, C11.+, D7.2 (ANODE), IC1.2 (VDD), IC2.5 (VOUT), J3.2, J4.P4 (VDD), Q2.3 (D), R1.1, R1_PINH1.2, R2-PINH1.2, R5.2, R6.2, R7.2, R8.2, R9.2, R10.2, R_BOOT.1, R_CHANGE.1, R_CL1.1, R_RESET.1, TP16.TP, U1.3 (!WP!(IO2)), U1.7 (!HOLD!/!RESET!(IO3)), U1.8 (VCC), U2.2 (3V3), U3.2 (VCC)
32KHZ: R2-PINH1.1, U2.9 (IO1), U3.1 (32KHZ)
DN: D1.4 (I/O2_2), J2.A7, J2.B7
DP: D1.6 (I/O1_2), J2.A6, J2.B6
EPD_3V3: C3.1, EPD_C5.1, J1.15, J1.16, L1.2, Q2.2 (S), TP17.TP
EPD_3V3_C: Q2.1 (G), R_CL1.2, TP13.TP, U2.18 (IO20)
EPD_BUSY: J1.9, TP9.TP, U2.26 (IO3)
EPD_CS: D6.2, J1.12, R9.1, TP10.TP, U2.11 (IO10)
EPD_DC: J1.11, TP11.TP, U2.5 (IO5)
EPD_RST: J1.10, TP12.TP, U2.21 (IO23)
FLASH_CS: D9.2, R5.1, U1.1 (!CS), U2.12 (IO11)
GND: BOOT_BUTTON.1, BOOT_BUTTON.2, C1.2, C1_BAT.2, C1_BAT1.2, C1_BAT2.2, C2.2, C2_BAT.2, C3.2, C4_USB.2, C5.2, C5_USB.2, C6.2, C7.2, C8.2, C10.2, C10_SUPERCAP.2, C11.-, CHANGE_BUTTON.1, CHANGE_BUTTON.2, C_DELAY.2, D1.2 (GND), D3.1 (K), D6.1, D8.1, D9.1, D10.1, D11.1, D12.1, EPD_C1.2, EPD_C2.2, EPD_C5.2, EPD_C6.2, EPD_C7.2, EPD_C8.2, EPD_C9.2, EPD_C10.2, EPD_C11.2, EPD_C12.2, IC1.3 (GND), IC2.2 (VSS), J1.8, J1.17, J1.MP1, J1.MP2, J2.A1, J2.A12, J2.B1, J2.B12, J2.MP1, J2.MP2, J2.MP3, J2.MP4, J3.1, J4.G1 (GND_1), J4.G2 (GND_2), J4.G3 (GND_3), J4.G4 (GND_4), J4.P6 (VSS), MCP73831.2 (VSS), R1_PWRUSB.1, R2.1, R2-USB.2, R2-USB1.1, R2_BAT.1, R4.2, RESET_BUTTON.1, RESET_BUTTON.2, SENSOR2.1 (GND), SENSOR2.5 (SDO), SENSOR2.7 (GND), SJ1.1, TP4.TP, TP5.TP, U1.4 (GND), U1.9 (EXP), U2.1 (GND), U2.28 (GND), U2.29_1 (GND), U2.29_2 (GND), U2.29_3 (GND), U2.29_4 (GND), U2.29_5 (GND), U2.29_6 (GND), U2.29_7 (GND), U2.29_8 (GND), U2.29_9 (GND), U3.13 (GND), U4.1 (CTG), U4.4 (GND), U4.6 (QSTRT), U4.9 (EP)
I2C_PW: C1.1, C2.1, R1_PINH.2, R2-PINH.2, SENSOR2.2 (CSB), SENSOR2.6 (VDDIO), SENSOR2.8 (VDD), U2.17 (IO19)
INT_RTC: R1_PINH1.1, TP15.TP, U2.8 (IO0), U3.3 (SQW/!INT)
IO/CHANGE: C10.1, CHANGE_BUTTON.3, CHANGE_BUTTON.4, R_CHANGE.2, U2.23 (IO15)
MISO: D12.2, J4.P7 (DAT0), R8.1, TP6.TP, U1.2 (DO(IO1)), U2.27 (IO2)
MOSI: D11.2, J1.14, J4.P3 (CMD), R7.1, TP7.TP, U1.5 (DI(IO0)), U2.7 (IO7)
unnamed: EPD_C1.1, J1.4
unnamed: EPD_C2.1, J1.5
unnamed: D7.1 (CATHODE), R_CAPACITOR.2
unnamed: EPD_C6.1, J1.18
unnamed: EPD_C7.1, J1.19
unnamed: EPD_C8.1, J1.20
unnamed: C_DELAY.1, IC1.5 (CT)
unnamed: EPD_C10.1, J1.22
unnamed: C4.1, D3.2 (A), D4.1 (K)
unnamed: EPD_C12.1, J1.24
unnamed: J2.B5, R2-USB.1
unnamed: MCP73831.1 (STAT), R1_BAT.2
unnamed: CHG_LED.C, R1_BAT.1
unnamed: MCP73831.5 (PROG), R2_BAT.2
unnamed: C1_BAT1.1, D2.1 (CATHODE), IC2.1 (VIN), IC2.3 (CE), Q3.2 (S)
unnamed: J2.A5, R2-USB1.2
PREVGH: D5.1 (K), EPD_C9.1, J1.21
PREVGL: D4.2 (A), EPD_C11.1, J1.23
RESE: J1.3, Q1.2 (S), R3.1
RESE': R2.2, R3.2, SJ1.2
RESET: C5.1, IC1.1 (VOUT), RESET_BUTTON.3, RESET_BUTTON.4, R_RESET.2, U2.3 (EN)
RTC_RST: U2.16 (IO18), U3.4 (!RST)
RX: TP2.TP, U2.24 (RXD0/GPIO17)
SCK: D10.2, J1.13, J4.P5 (CLK), R6.1, TP8.TP, U1.6 (CLK), U2.6 (IO6)
SCL: J3.4, R2-PINH.1, SENSOR2.4 (SCK), U2.20 (IO22), U3.16 (SCL), U4.7 (SCL)
SDA: J3.3, R1_PINH.1, SENSOR2.3 (SDI), U2.19 (IO21), U3.15 (SDA), U4.8 (SDA)
SRC: C4.2, D5.2 (A), L1.1, Q1.3 (D)
SS_SD: D8.2, J4.P2 (CD/DAT3), R10.1, U2.4 (IO4)
TX: TP1.TP, U2.25 (TXD0/GPIO16)
USB_D+: D1.1 (I/O1_1), U2.14 (IO13)
USB_D-: D1.3 (I/O2_1), U2.13 (IO12)
VBAT: C2_BAT.1, MCP73831.3 (VBAT), Q3.3 (D), TP3.TP, U4.2 (CELL), U4.3 (VDD)
VBUS: C1_BAT.1, C4_USB.1, C5_USB.1, CHG_LED.A, D1.5 (VBUS), D2.2 (ANODE), MCP73831.4 (VIN), PFMF.050.1.2, Q3.1 (G), R1_PWRUSB.2, TP14.TP
VRTC: C8.1, C10_SUPERCAP.1, R_CAPACITOR.1, U3.14 (VBAT)
VUSB: J2.A4, J2.A9, J2.B4, J2.B9, PFMF.050.1.1

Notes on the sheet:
E-Paper Display Header
RTC Module DS3231SN
Test Pads
Qwiic / Stemma QT
SPI ESD Protection Lines
External NOR Flash 64MB
Battery Charge Level
Voltage Supervisor + Reset & Boot / IO Button
Environmental Sensor BME688
EPD Power
Display Type Selector
E-Paper Drive Circuit
Li-Po Battery Charging Controller
ESP32 C6
SD Card
LDO Voltage Regulator
USB C connector & ESD protection
OpenBook Schematic
drawn by: Iacob Ioana-Delia

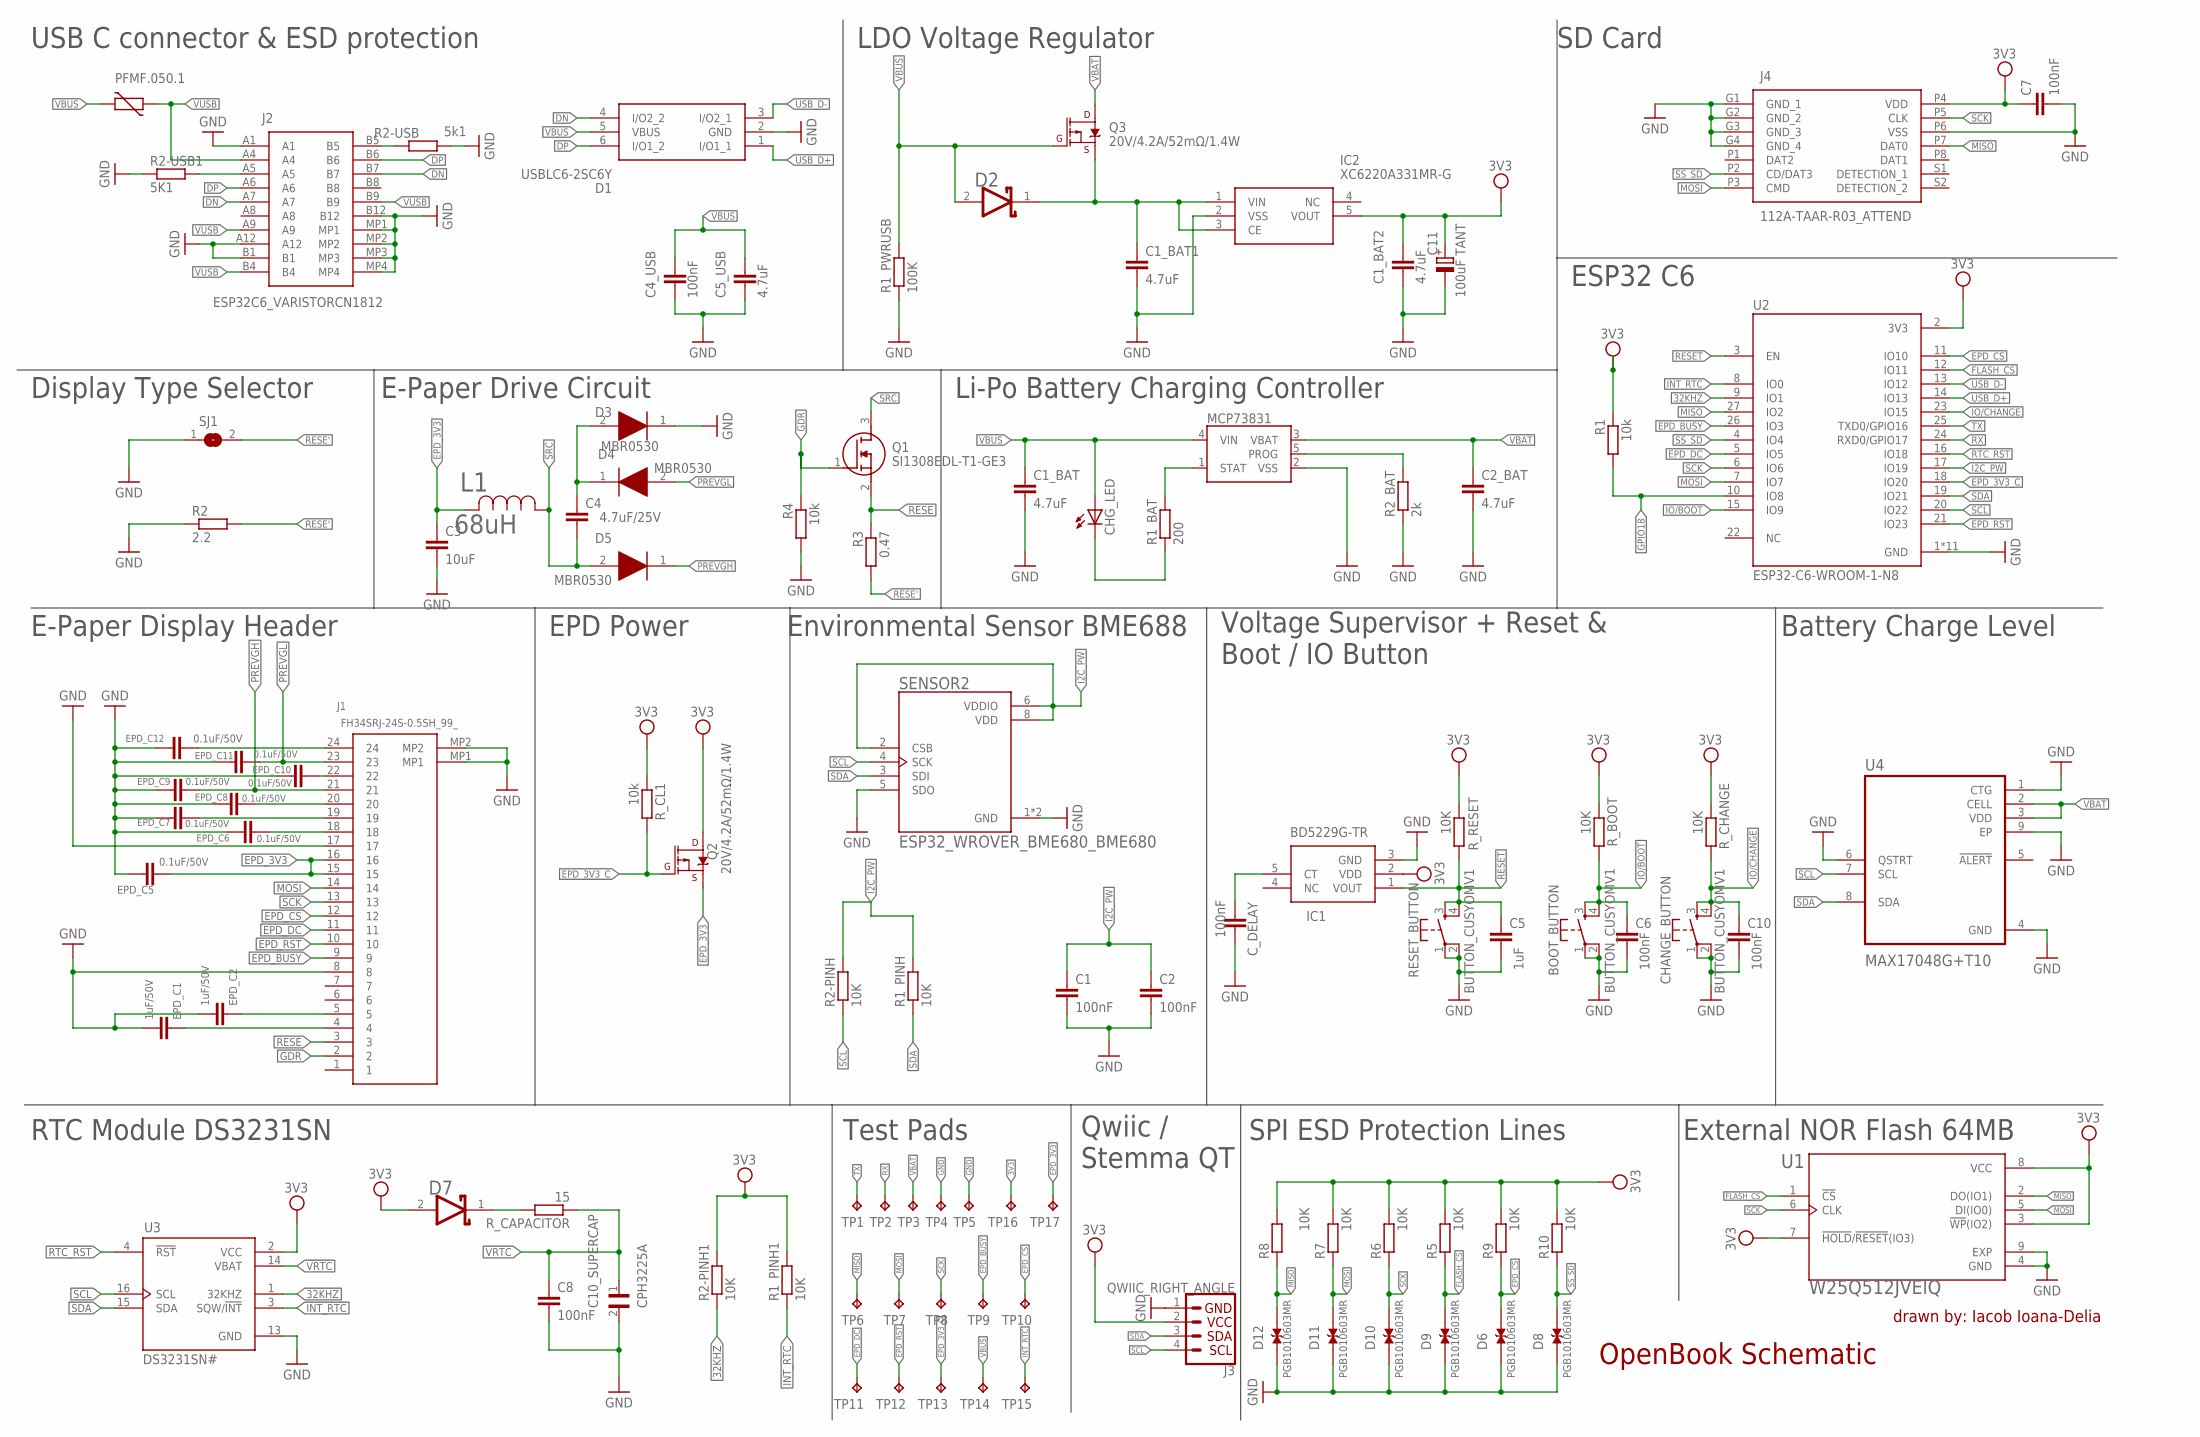
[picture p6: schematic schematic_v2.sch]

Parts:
BOOT_BUTTON: BUTTON_CUSYOMV1; MYBUTTON
C1, C2, C4_USB, C6, C7, C8, C10: 100nF; ESP32_WROVER_EAGLE-LTSPICE_C0402
C1_BAT, C1_BAT1, C1_BAT2, C2_BAT, C5_USB: 4.7uF; ESP32_WROVER_EAGLE-LTSPICE_C0402
C3: 10uF; ESP32_WROVER_EAGLE-LTSPICE_C0402
C4: 4.7uF/25V; ESP32_WROVER_EAGLE-LTSPICE_C0402
C5: 1uF; ESP32_WROVER_EAGLE-LTSPICE_C0402
C10_SUPERCAP: CPH3225A; CAPCP3225X100N
C11: 100uF TANT; RCL_CT3528
CHANGE_BUTTON: BUTTON_CUSYOMV1; MYBUTTON
CHG_LED: ADAFRUIT_LEDCHIP-LED0603; ADAFRUIT_CHIP-LED0603
C_DELAY: 100nF; ESP32_WROVER_EAGLE-LTSPICE_C0402
D1: USBLC6-2SC6Y; SOT95P280X145-6N
D2, D7: ESP32_WROVER_AVX---SD0805S020S1R0_AVX_SD0805S020S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; ESP32_WROVER_AVX---SD0805S020S1R0_AVX_SD0805S020S1R0_0
D3, D4, D5: MBR0530; SOD3716X135N
D6, D8, D9, D10, D11, D12: PGB1010603MR; DIOC1608X36N
EPD_C1, EPD_C2: 1uF/50V; ESP32_WROVER_EAGLE-LTSPICE_C0402
EPD_C5, EPD_C6, EPD_C7, EPD_C8, EPD_C9, EPD_C10, EPD_C11, EPD_C12: 0.1uF/50V; ESP32_WROVER_EAGLE-LTSPICE_C0402
IC1: BD5229G-TR; SOT95P280X125-5N
IC2: XC6220A331MR-G; SOT95P280X120-5N
J1: FH34SRJ-24S-0.5SH_99_; FH34SRJ24S05SH99
J2: SAMACSYS_PARTS_USB4110-GF-A; SAMACSYS_PARTS_USB4110GFA
J3: QWIIC_RIGHT_ANGLE; JST04_1MM_RA
J4: 112A-TAAR-R03_ATTEND; 112ATAARR03ATTEND
L1: 68uH; IND_4828-WE-TPC_WRE
MCP73831: ESP32_WROVER_SPARKFUN-IC-POWER_MCP73831; ESP32_WROVER_SPARKFUN-IC-POWER_SOT23-5
PFMF.050.1: ESP32C6_VARISTORCN1812; ESP32C6_VARISTOR_CT/CN1812
Q1: SI1308EDL-T1-GE3; SOT65P210X110-3N
Q2, Q3: 20V/4.2A/52mΩ/1.4W; ESP32_WROVER_SPARKFUN-DISCRETESEMI_SOT23-3
R1, R4: 10k; ESP32_WROVER_EAGLE-LTSPICE_R0402
R1_BAT: 200; ESP32_WROVER_EAGLE-LTSPICE_R0402
R1_PINH, R1_PINH1, R2-PINH, R2-PINH1, R5, R6, R7, R8, R9, R10: 10K; ESP32_WROVER_EAGLE-LTSPICE_R0402
R1_PWRUSB: 100K; ESP32_WROVER_EAGLE-LTSPICE_R0402
R2: 2.2; ESP32_WROVER_EAGLE-LTSPICE_R0402
R2-USB: 5k1; ESP32_WROVER_EAGLE-LTSPICE_R0402
R2-USB1: 5K1; ESP32_WROVER_EAGLE-LTSPICE_R0402
R2_BAT: 2k; ESP32_WROVER_EAGLE-LTSPICE_R0402
R3: 0.47; ESP32_WROVER_EAGLE-LTSPICE_R0402
RESET_BUTTON: BUTTON_CUSYOMV1; MYBUTTON
R_BOOT: 10K; ESP32_WROVER_EAGLE-LTSPICE_R0402
R_CAPACITOR: 15; ESP32_WROVER_EAGLE-LTSPICE_R0402
R_CHANGE: 10K; ESP32_WROVER_EAGLE-LTSPICE_R0402
R_CL1: 10k; ESP32_WROVER_EAGLE-LTSPICE_R0402
R_RESET: 10K; ESP32_WROVER_EAGLE-LTSPICE_R0402
SENSOR2: ESP32_WROVER_BME680_BME680; ESP32_WROVER_BME680_PSON80P300X300X100-8N
SJ1: SJ
TP1, TP2, TP3, TP4, TP5, TP6, TP7, TP8, TP9, TP10, TP11, TP12, TP13, TP14, TP15, TP16, TP17: TPTP20R; TP20R
U1: W25Q512JVEIQ; SON127P600X800X80-9N
U2: ESP32-C6-WROOM-1-N8; XCVR_ESP32-C6-WROOM-1-N8
U3: DS3231SN#; SOIC127P1032X265-16N
U4: MAX17048G+T10; SON50P200X200X80-9N

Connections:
3V3: C1_BAT2.1, C7.1, C11.+, D7.2 (ANODE), IC1.2 (VDD), IC2.5 (VOUT), J3.2, J4.P4 (VDD), Q2.3 (D), R1.1, R1_PINH1.2, R2-PINH1.2, R5.2, R6.2, R7.2, R8.2, R9.2, R10.2, R_BOOT.1, R_CHANGE.1, R_CL1.1, R_RESET.1, TP16.TP, U1.3 (!WP!(IO2)), U1.7 (!HOLD!/!RESET!(IO3)), U1.8 (VCC), U2.2 (3V3), U3.2 (VCC)
32KHZ: R2-PINH1.1, U2.9 (IO1), U3.1 (32KHZ)
DN: D1.4 (I/O2_2), J2.A7, J2.B7
DP: D1.6 (I/O1_2), J2.A6, J2.B6
EPD_3V3: C3.1, EPD_C5.1, J1.15, J1.16, L1.2, Q2.2 (S), TP17.TP
EPD_3V3_C: Q2.1 (G), R_CL1.2, TP13.TP, U2.18 (IO20)
EPD_BUSY: J1.9, TP9.TP, U2.26 (IO3)
EPD_CS: D6.2, J1.12, R9.1, TP10.TP, U2.11 (IO10)
EPD_DC: J1.11, TP11.TP, U2.5 (IO5)
EPD_RST: J1.10, TP12.TP, U2.21 (IO23)
FLASH_CS: D9.2, R5.1, U1.1 (!CS), U2.12 (IO11)
GND: BOOT_BUTTON.1, BOOT_BUTTON.2, C1.2, C1_BAT.2, C1_BAT1.2, C1_BAT2.2, C2.2, C2_BAT.2, C3.2, C4_USB.2, C5.2, C5_USB.2, C6.2, C7.2, C8.2, C10.2, C10_SUPERCAP.2, C11.-, CHANGE_BUTTON.1, CHANGE_BUTTON.2, C_DELAY.2, D1.2 (GND), D3.1 (K), D6.1, D8.1, D9.1, D10.1, D11.1, D12.1, EPD_C1.2, EPD_C2.2, EPD_C5.2, EPD_C6.2, EPD_C7.2, EPD_C8.2, EPD_C9.2, EPD_C10.2, EPD_C11.2, EPD_C12.2, IC1.3 (GND), IC2.2 (VSS), J1.8, J1.17, J1.MP1, J1.MP2, J2.A1, J2.A12, J2.B1, J2.B12, J2.MP1, J2.MP2, J2.MP3, J2.MP4, J3.1, J4.G1 (GND_1), J4.G2 (GND_2), J4.G3 (GND_3), J4.G4 (GND_4), J4.P6 (VSS), MCP73831.2 (VSS), R1_PWRUSB.1, R2.1, R2-USB.2, R2-USB1.1, R2_BAT.1, R4.2, RESET_BUTTON.1, RESET_BUTTON.2, SENSOR2.1 (GND), SENSOR2.5 (SDO), SENSOR2.7 (GND), SJ1.1, TP4.TP, TP5.TP, U1.4 (GND), U1.9 (EXP), U2.1 (GND), U2.28 (GND), U2.29_1 (GND), U2.29_2 (GND), U2.29_3 (GND), U2.29_4 (GND), U2.29_5 (GND), U2.29_6 (GND), U2.29_7 (GND), U2.29_8 (GND), U2.29_9 (GND), U3.13 (GND), U4.1 (CTG), U4.4 (GND), U4.6 (QSTRT), U4.9 (EP)
I2C_PW: C1.1, C2.1, R1_PINH.2, R2-PINH.2, SENSOR2.2 (CSB), SENSOR2.6 (VDDIO), SENSOR2.8 (VDD), U2.17 (IO19)
INT_RTC: R1_PINH1.1, TP15.TP, U2.8 (IO0), U3.3 (SQW/!INT)
IO/CHANGE: C10.1, CHANGE_BUTTON.3, CHANGE_BUTTON.4, R_CHANGE.2, U2.23 (IO15)
MISO: D12.2, J4.P7 (DAT0), R8.1, TP6.TP, U1.2 (DO(IO1)), U2.27 (IO2)
MOSI: D11.2, J1.14, J4.P3 (CMD), R7.1, TP7.TP, U1.5 (DI(IO0)), U2.7 (IO7)
unnamed: EPD_C1.1, J1.4
unnamed: EPD_C2.1, J1.5
unnamed: D7.1 (CATHODE), R_CAPACITOR.2
unnamed: EPD_C6.1, J1.18
unnamed: EPD_C7.1, J1.19
unnamed: EPD_C8.1, J1.20
unnamed: C_DELAY.1, IC1.5 (CT)
unnamed: EPD_C10.1, J1.22
unnamed: C4.1, D3.2 (A), D4.1 (K)
unnamed: EPD_C12.1, J1.24
unnamed: J2.B5, R2-USB.1
unnamed: MCP73831.1 (STAT), R1_BAT.2
unnamed: CHG_LED.C, R1_BAT.1
unnamed: MCP73831.5 (PROG), R2_BAT.2
unnamed: C1_BAT1.1, D2.1 (CATHODE), IC2.1 (VIN), IC2.3 (CE), Q3.2 (S)
unnamed: J2.A5, R2-USB1.2
PREVGH: D5.1 (K), EPD_C9.1, J1.21
PREVGL: D4.2 (A), EPD_C11.1, J1.23
RESE: J1.3, Q1.2 (S), R3.1
RESE': R2.2, R3.2, SJ1.2
RESET: C5.1, IC1.1 (VOUT), RESET_BUTTON.3, RESET_BUTTON.4, R_RESET.2, U2.3 (EN)
RTC_RST: U2.16 (IO18), U3.4 (!RST)
RX: TP2.TP, U2.24 (RXD0/GPIO17)
SCK: D10.2, J1.13, J4.P5 (CLK), R6.1, TP8.TP, U1.6 (CLK), U2.6 (IO6)
SCL: J3.4, R2-PINH.1, SENSOR2.4 (SCK), U2.20 (IO22), U3.16 (SCL), U4.7 (SCL)
SDA: J3.3, R1_PINH.1, SENSOR2.3 (SDI), U2.19 (IO21), U3.15 (SDA), U4.8 (SDA)
SRC: C4.2, D5.2 (A), L1.1, Q1.3 (D)
SS_SD: D8.2, J4.P2 (CD/DAT3), R10.1, U2.4 (IO4)
TX: TP1.TP, U2.25 (TXD0/GPIO16)
USB_D+: D1.1 (I/O1_1), U2.14 (IO13)
USB_D-: D1.3 (I/O2_1), U2.13 (IO12)
VBAT: C2_BAT.1, MCP73831.3 (VBAT), Q3.3 (D), TP3.TP, U4.2 (CELL), U4.3 (VDD)
VBUS: C1_BAT.1, C4_USB.1, C5_USB.1, CHG_LED.A, D1.5 (VBUS), D2.2 (ANODE), MCP73831.4 (VIN), PFMF.050.1.2, Q3.1 (G), R1_PWRUSB.2, TP14.TP
VRTC: C8.1, C10_SUPERCAP.1, R_CAPACITOR.1, U3.14 (VBAT)
VUSB: J2.A4, J2.A9, J2.B4, J2.B9, PFMF.050.1.1

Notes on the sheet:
E-Paper Display Header
RTC Module DS3231SN
Test Pads
Qwiic / Stemma QT
SPI ESD Protection Lines
External NOR Flash 64MB
Battery Charge Level
Voltage Supervisor + Reset & Boot / IO Button
Environmental Sensor BME688
EPD Power
Display Type Selector
E-Paper Drive Circuit
Li-Po Battery Charging Controller
ESP32 C6
SD Card
LDO Voltage Regulator
USB C connector & ESD protection
OpenBook Schematic
drawn by: Iacob Ioana-Delia

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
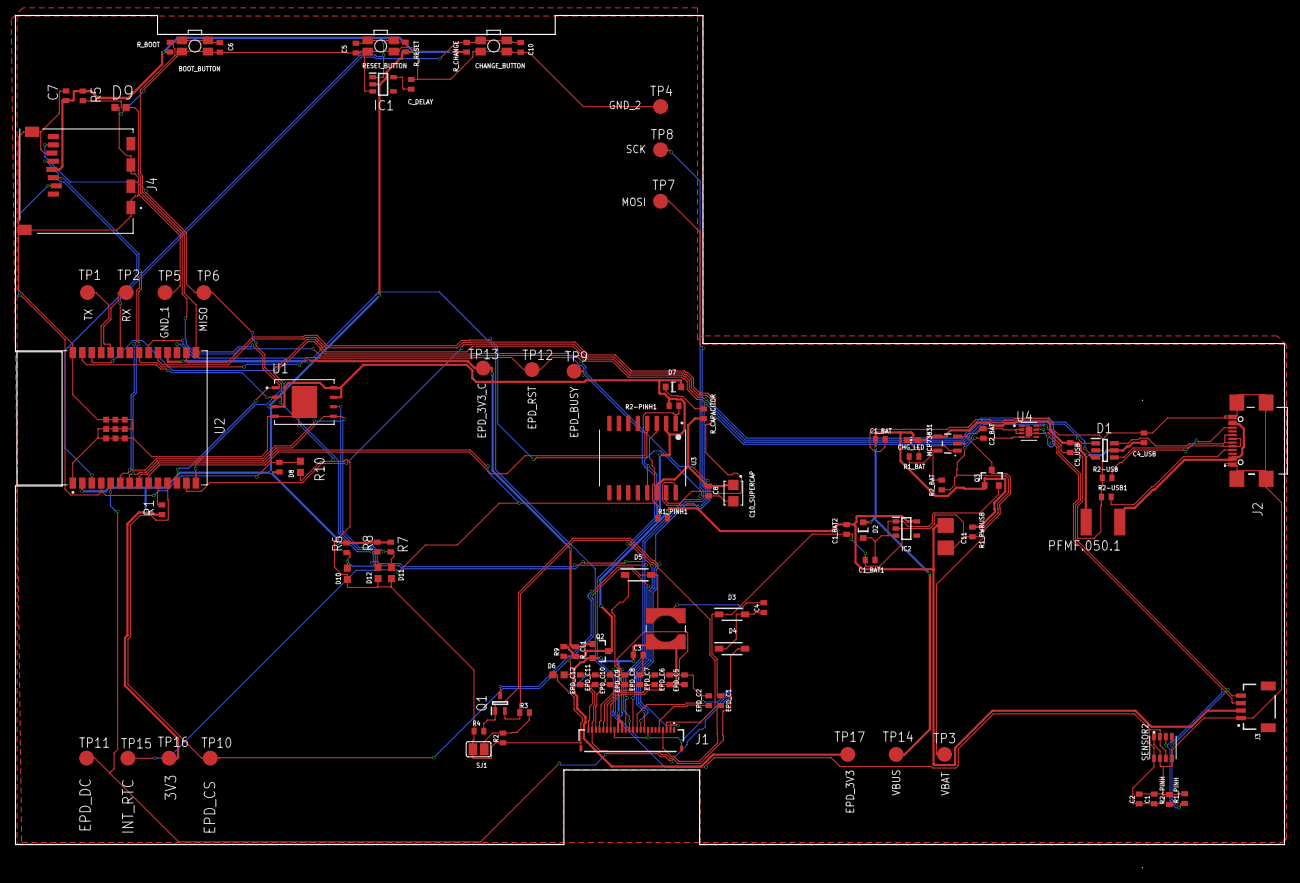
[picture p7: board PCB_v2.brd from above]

Board: 2 copper layers, 170.2 x 114.3 mm, 103 parts (0 on the bottom side), 55 nets.

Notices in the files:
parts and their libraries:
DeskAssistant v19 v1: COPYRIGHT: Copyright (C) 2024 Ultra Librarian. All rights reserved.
